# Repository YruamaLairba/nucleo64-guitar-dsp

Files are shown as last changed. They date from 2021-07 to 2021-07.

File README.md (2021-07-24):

# Nucleo guitar DSP

A STM32 Nucleo expansion board to transform your Nucleo board into guitar effect
processor.

## Description

This is a STM32 Nucleo expansion board to turn Nucleo Development board into
a guitar effect processor. It's designed targeting specifically the
nucleo-f441RE board while being usable with other boards, so it may be usable
with most nucleo64 and nucleo144 board.

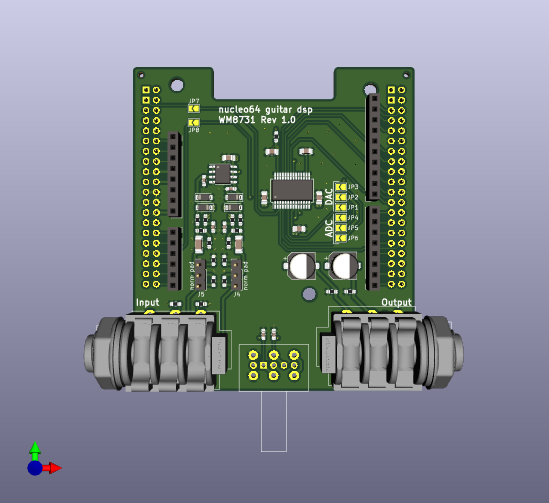
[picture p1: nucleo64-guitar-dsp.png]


## Some features:
 * can be used with passive or active guitar, thanks to j4 and j5 selectors
   (mini switches can be used instead of pin headers and jumpers).
   * "norm" is for passive guitar and voltage source below 1vrms. Input
     impedance is ~1 Megohm
   * "pad" is for active source with voltage higher than 1vrms, It apply ~18db
     attenuation. Input impedance is 37 ~ 38kohm.
   * J4 is for left channel and J5 for the right channel. 
 * Stereo input, so it can be used for stuff other than guitar.
 * Output usable with headphone.

## Setup solder bridge

I assume a Nucleo-f411re board. Depending the used Nucleo board, pinout can be
different and things can have different name or may even not exist. Check
various datasheet before doing anything.

JP1 - JP3, connect ADC output to a i2s serial data pin:
 * JP1 connects to PB15 (I2S2_SD)
 * JP2 connects to PB14 (I2S2ext_SD)
 * JP3 connects to PC12 (I2S3_SD)

JP4 - JP6, connect DAC input to a i2s serial data pin:
 * JP4 connects to PB15 (I2S2_SD)
 * JP5 connects to PB14 (I2S2ext_SD)
 * JP6 connects to PC12 (I2S3_SD)

JP7, connect PB13 (I2S2_CK) and PC10 (I2S3_CK), required when I2S3 is used

JP8, connect PB12 (I2S2_WS) and PA4 (I2S3_WS), required when I2S3 is used

Note: only I2S2 peripheral can be used as master.

## Missed consideration
In this first version, i missed or forgot some consideration:

 * **No output to output protection:** it mean boards can be damaged by a wrong
   setup. Putting resistor instead soldebridge on some solder jumper reduce the
risk

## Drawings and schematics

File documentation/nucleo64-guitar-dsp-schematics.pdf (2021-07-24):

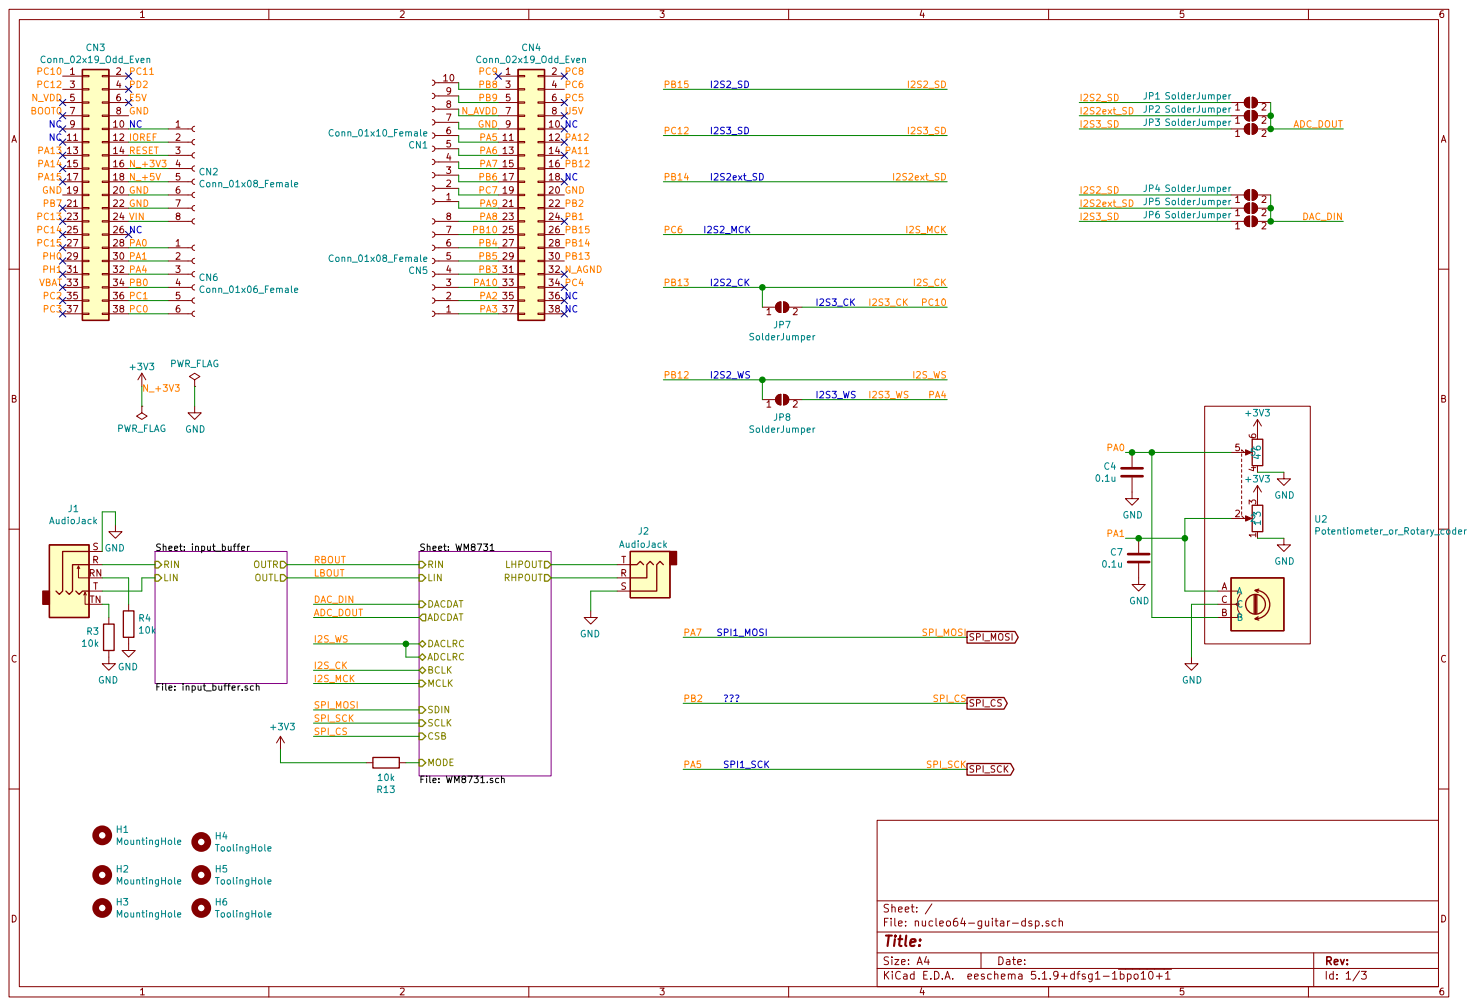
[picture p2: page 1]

File: nucleo64-guitar-dsp.sch Sheet: / Sheet: input_buffer
File: input_buffer.sch OUTR OUTL RIN
LIN

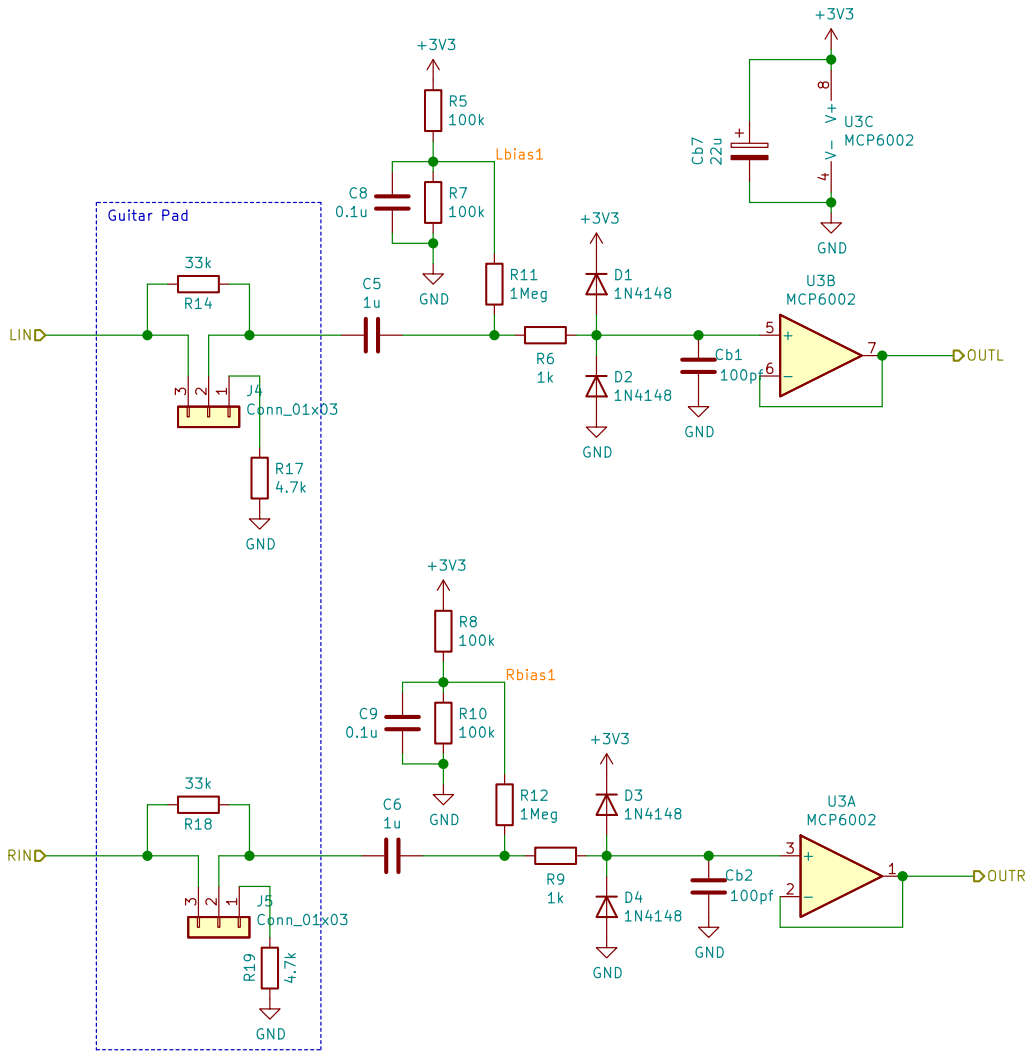
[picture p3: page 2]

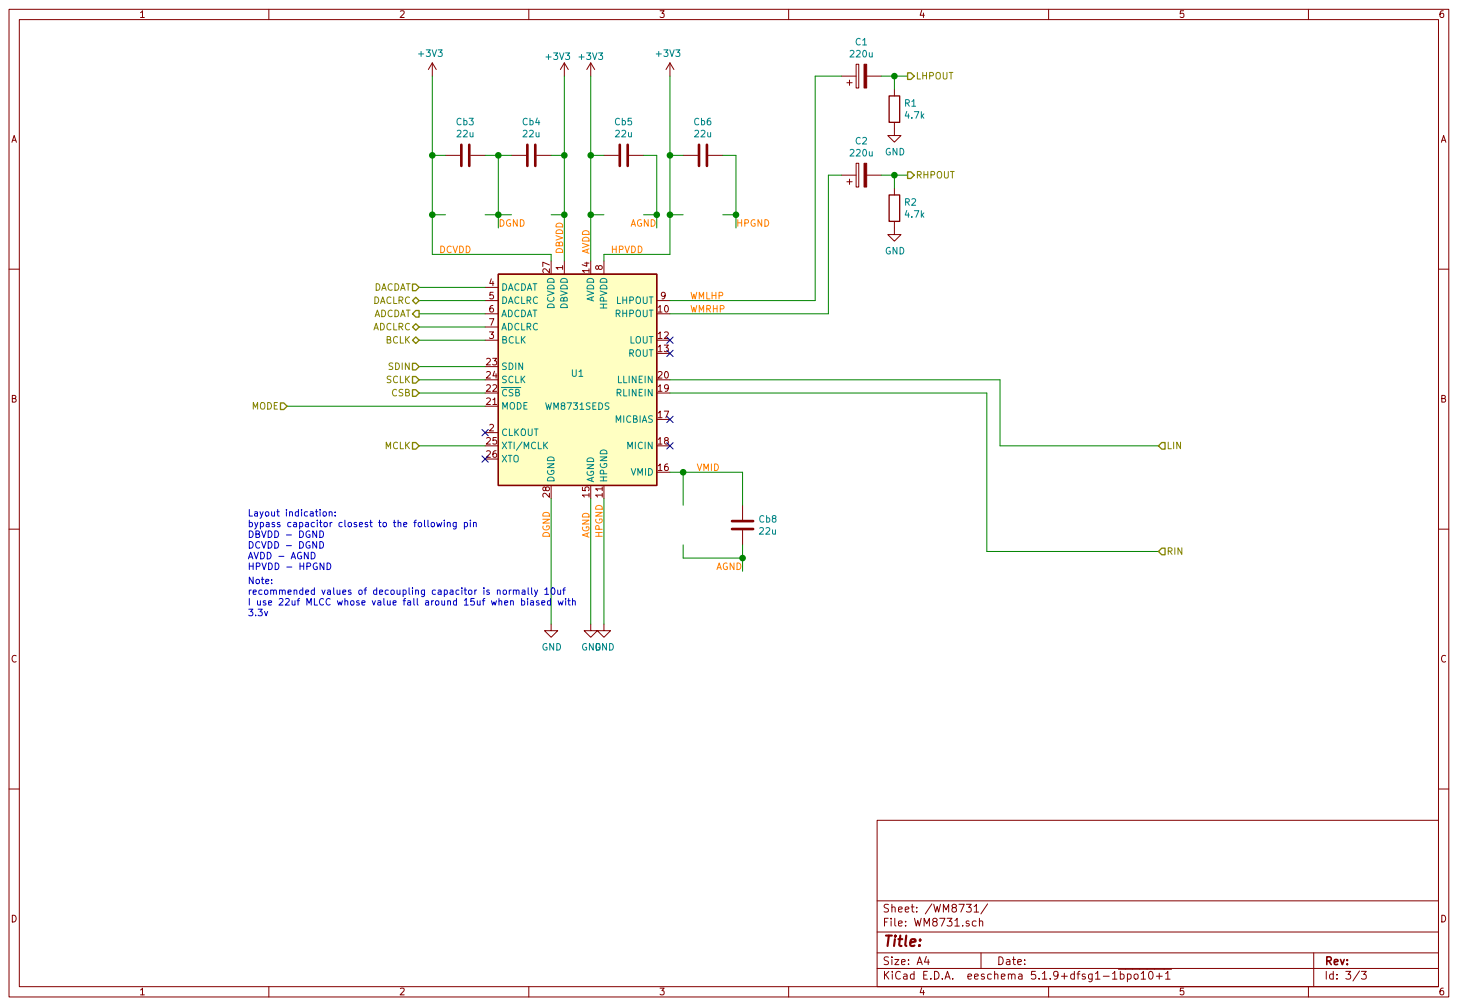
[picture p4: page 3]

3.3v Layout indication:
bypass capacitor closest to the following pin DBVDD - DGND

DCVDD - DGND
AVDD - AGND
HPVDD - HPGND
Note: recommended values of decoupling capacitor is normally 10uf

I use 22uf MLCC whose value fall around 15uf when biased with

Id: 3/3 Title: File: WM8731.sch Sheet: /WM8731/ GND

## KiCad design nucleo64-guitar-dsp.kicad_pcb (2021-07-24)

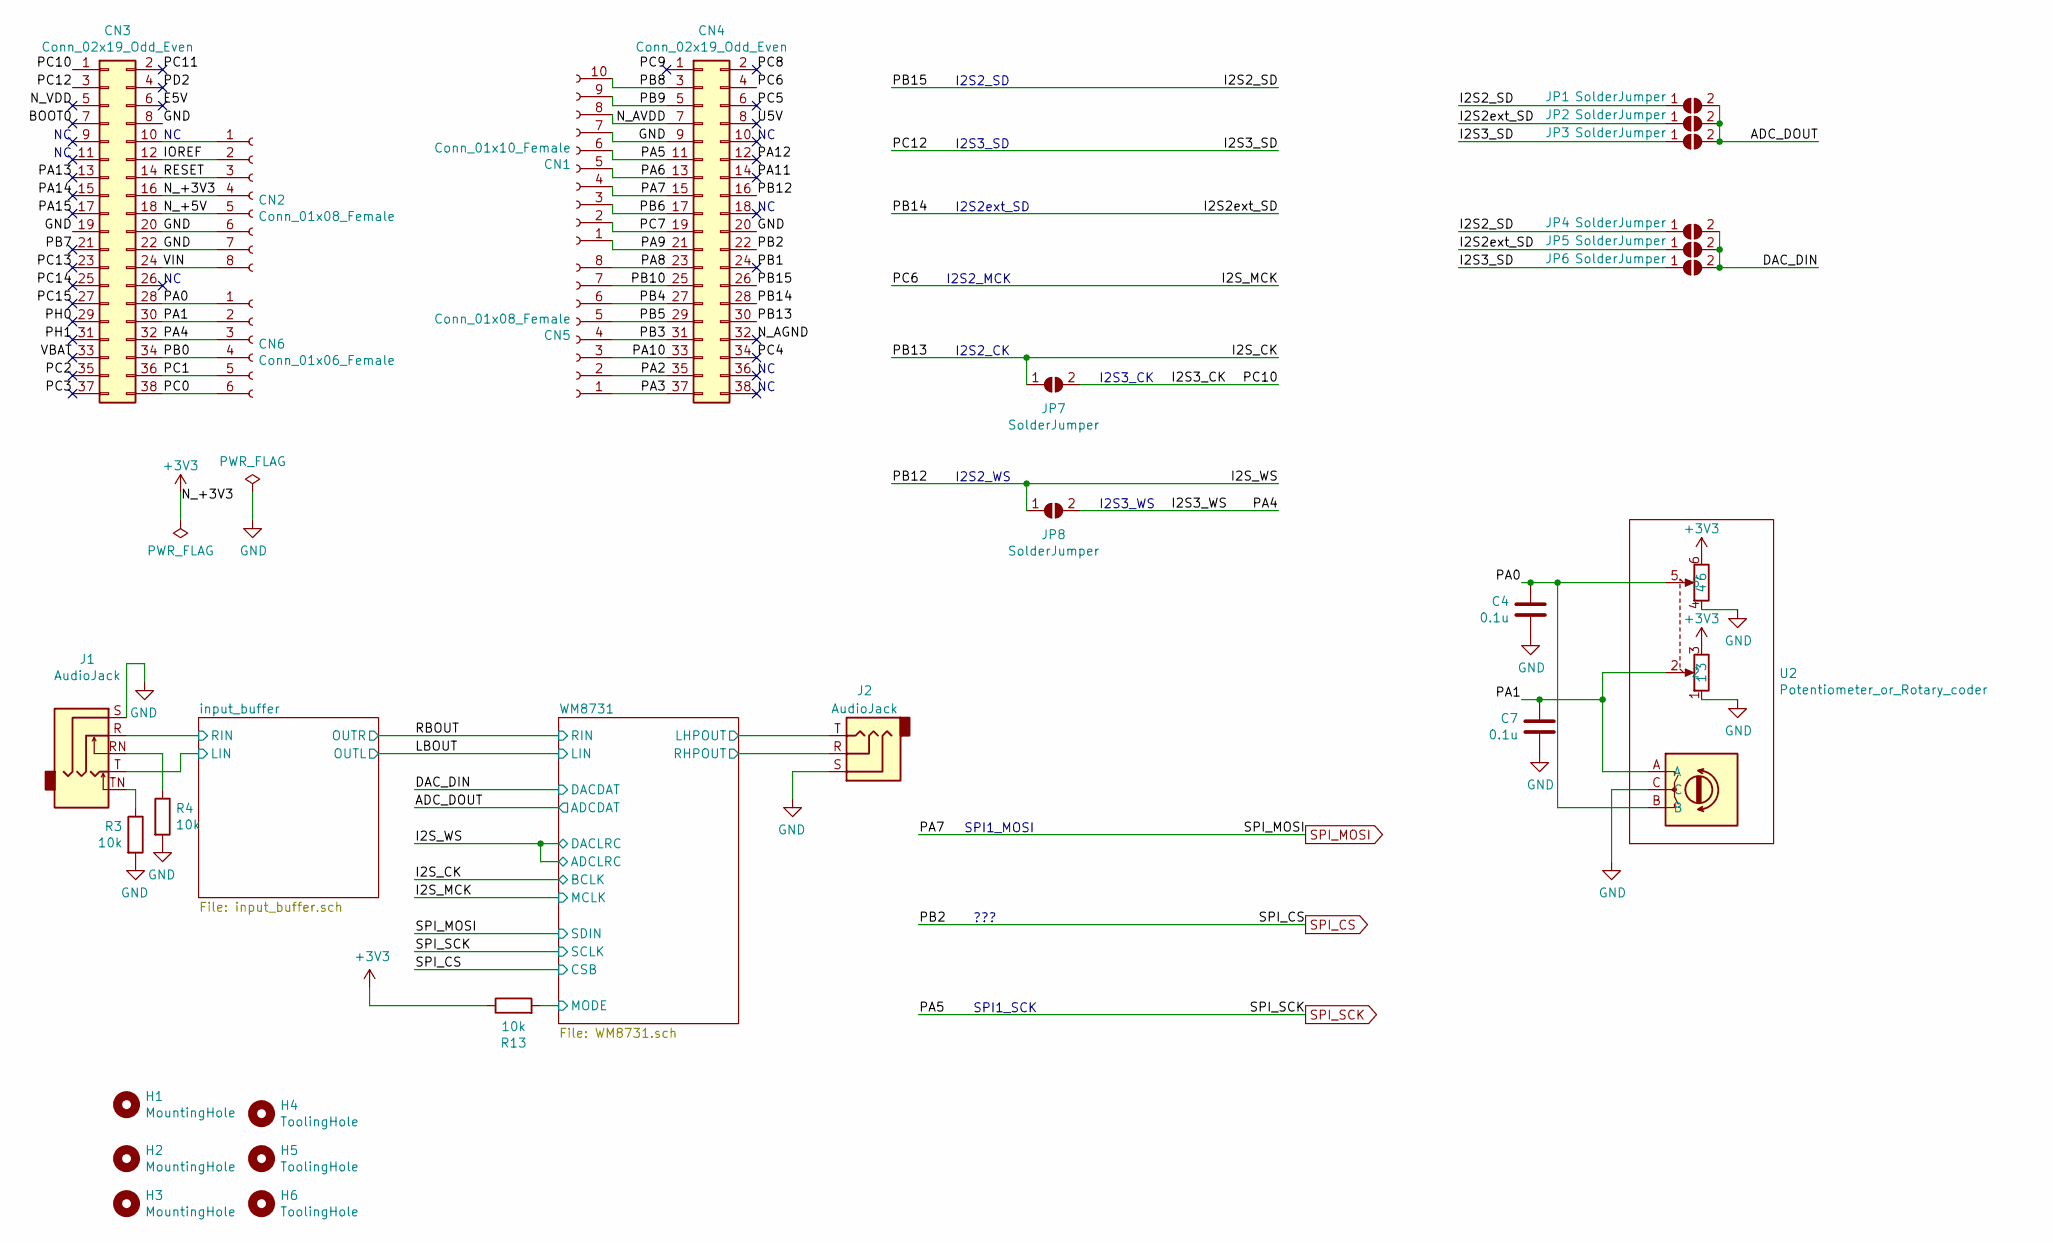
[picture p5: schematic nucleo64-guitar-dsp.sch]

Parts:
C4, C7: 0.1u; C_0603_1608Metric_Pad1.08x0.95mm_HandSolder; LCSC Part C14663
CN1: Conn_01x10_Female; PinSocket_1x10_P2.54mm_Vertical
CN2, CN5: Conn_01x08_Female; PinSocket_1x08_P2.54mm_Vertical
CN3, CN4: Conn_02x19_Odd_Even; PinSocket_2x19_P2.54mm_Vertical
CN6: Conn_01x06_Female; PinSocket_1x06_P2.54mm_Vertical
H1, H2, H3: MountingHole; MountingHole_3.2mm_M3_ISO14580
H4, H5, H6: ToolingHole; JLCPCB_2_layer
J1, J2: AudioJack; Jack_6.35mm_Neutrik_NM+NR
JP1, JP2, JP3, JP4, JP5, JP6, JP7, JP8: SolderJumper; SolderJumper-2_P1.3mm_Open_TrianglePad1.0x1.5mm
R3, R4, R13: 10k; R_0603_1608Metric_Pad0.98x0.95mm_HandSolder; LCSC Part C25804
U2: Potentiometer_or_Rotary_coder; Potentiometer_or_Rotary_Encoder

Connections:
+3V3: CN2.4, CN3.16, R13.1, U2.3, U2.6; also elsewhere on the board
/ADC_DOUT: JP1.2 (B), JP2.2 (B), JP3.2 (B); also elsewhere on the board
/BOOT0: CN3.7
/DAC_DIN: JP4.2 (B), JP5.2 (B), JP6.2 (B); also elsewhere on the board
/E5V: CN3.6
/I2S2_SD: CN4.26, JP1.1 (A), JP4.1 (A)
/I2S2ext_SD: CN4.28, JP2.1 (A), JP5.1 (A)
/I2S3_CK: CN3.1, JP7.2 (B)
/I2S3_SD: CN3.3, JP3.1 (A), JP6.1 (A)
/I2S3_WS: CN3.32, CN6.3, JP8.2 (B)
/I2S_CK: CN4.30, JP7.1 (A); also elsewhere on the board
/I2S_MCK: CN4.4; also elsewhere on the board
/I2S_WS: CN4.16, JP8.1 (A); also elsewhere on the board
/IOREF: CN2.2, CN3.12
/N_+5V: CN2.5, CN3.18
/N_AGND: CN4.32
/N_AVDD: CN1.8, CN4.7
/N_VDD: CN3.5
/PA0: C4.1, CN3.28, CN6.1, U2.5, U2.B
/PA1: C7.1, CN3.30, CN6.2, U2.2, U2.A
/PA2: CN4.35, CN5.2
/PA3: CN4.37, CN5.1
/PA6: CN1.5, CN4.13
/PA8: CN4.23, CN5.8
/PA9: CN1.1, CN4.21
/PA10: CN4.33, CN5.3
/PA11: CN4.14
/PA12: CN4.12
/PA13: CN3.13
/PA14: CN3.15
/PA15: CN3.17
/PB0: CN3.34, CN6.4
/PB1: CN4.24
/PB3: CN4.31, CN5.4
/PB4: CN4.27, CN5.6
/PB5: CN4.29, CN5.5
/PB6: CN1.3, CN4.17
/PB7: CN3.21
/PB8: CN1.10, CN4.3
/PB9: CN1.9, CN4.5
/PB10: CN4.25, CN5.7
/PC0: CN3.38, CN6.6
/PC1: CN3.36, CN6.5
/PC2: CN3.35
/PC3: CN3.37
/PC4: CN4.34
/PC5: CN4.6
/PC7: CN1.2, CN4.19
/PC8: CN4.2
/PC9: CN4.1
/PC11: CN3.2
/PC13: CN3.23
/PC14: CN3.25
/PC15: CN3.27
/PD2: CN3.4
/PH0: CN3.29
/PH1: CN3.31
/RESET: CN2.3, CN3.14
/U5V: CN4.8
/VBAT: CN3.33
/VIN: CN2.8, CN3.24
/WM8731/LHPOUT: J2.T; also elsewhere on the board
/WM8731/MODE: R13.2; also elsewhere on the board
/WM8731/RHPOUT: J2.R; also elsewhere on the board
/input_buffer/LIN: J1.T; also elsewhere on the board
/input_buffer/RIN: J1.R; also elsewhere on the board
GND: C4.2, C7.2, CN1.7, CN2.6, CN2.7, CN3.8, CN3.19, CN3.20, CN3.22, CN4.9, CN4.20, J1.S, J2.S, R3.2, R4.2, U2.1, U2.4, U2.C; also elsewhere on the board
unnamed: CN2.1, CN3.10
unnamed: J1.RN, R4.1
unnamed: J1.TN, R3.1
SPI_CS: CN4.22; also elsewhere on the board
SPI_MOSI: CN1.4, CN4.15; also elsewhere on the board
SPI_SCK: CN1.6, CN4.11; also elsewhere on the board

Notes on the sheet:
I2S2_WS
I2S2_CK
I2S2ext_SD
I2S2_SD
I2S2_MCK
I2S3_WS
I2S3_CK
I2S3_SD
SPI1_SCK
???
SPI1_MOSI

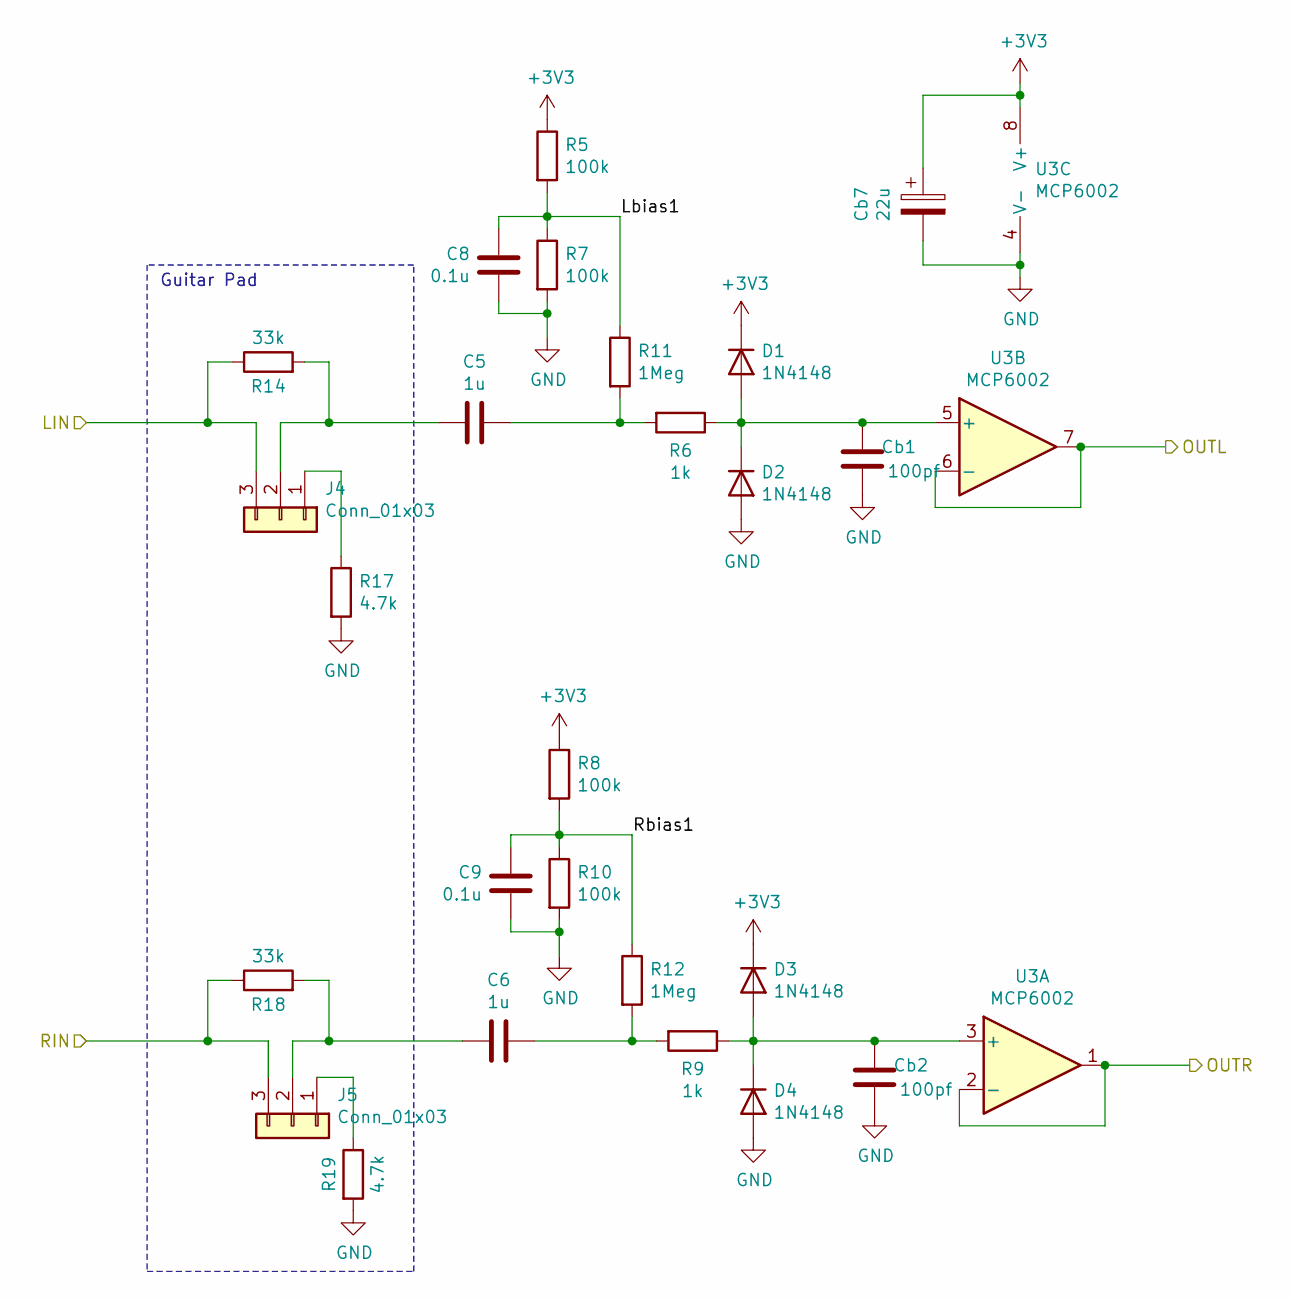
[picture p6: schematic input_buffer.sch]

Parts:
C5, C6: 1u; C_1206_3216Metric_Pad1.33x1.80mm_HandSolder; LCSC Part C1848
C8, C9: 0.1u; C_0603_1608Metric_Pad1.08x0.95mm_HandSolder; LCSC Part C14663
Cb1, Cb2: 100pf; C_0603_1608Metric_Pad1.08x0.95mm_HandSolder; LCSC Part C14858
Cb7: 22u; C_0805_2012Metric_Pad1.18x1.45mm_HandSolder; LCSC Part C45783
D1, D2, D3, D4: 1N4148; D_SOD-123; LCSC Part C81598
J4, J5: Conn_01x03; PinHeader_1x03_P2.54mm_Vertical
R5, R7, R8, R10: 100k; R_0603_1608Metric_Pad0.98x0.95mm_HandSolder; LCSC Part C22938
R6, R9: 1k; R_0603_1608Metric_Pad0.98x0.95mm_HandSolder; LCSC Part C21190
R11, R12: 1Meg; R_0603_1608Metric_Pad0.98x0.95mm_HandSolder; LCSC Part C22935
R14, R18: 33k; R_0603_1608Metric_Pad0.98x0.95mm_HandSolder; LCSC Part C4216
R17, R19: 4.7k; R_0603_1608Metric_Pad0.98x0.95mm_HandSolder; LCSC Part C23162
U3: MCP6002; SOIC-8_3.9x4.9mm_P1.27mm; LCSC Part C7377

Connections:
+3V3: Cb7.1, D1.1 (K), D3.1 (K), R5.1, R8.1, U3.8 (V+); also elsewhere on the board
/LBOUT: U3.6 (-), U3.7; also elsewhere on the board
/RBOUT: U3.1, U3.2 (-); also elsewhere on the board
/input_buffer/LIN: J4.3, R14.1; also elsewhere on the board
/input_buffer/Lbias1: C8.1, R5.2, R7.1, R11.1
/input_buffer/RIN: J5.3, R18.1; also elsewhere on the board
/input_buffer/Rbias1: C9.1, R8.2, R10.1, R12.1
GND: C8.2, C9.2, Cb1.1, Cb2.1, Cb7.2, D2.2 (A), D4.2 (A), R7.2, R10.2, R17.2, R19.2, U3.4 (V-); also elsewhere on the board
unnamed: C5.1, R6.2, R11.2
unnamed: C5.2, J4.2, R14.2
unnamed: C6.1, R9.2, R12.2
unnamed: C6.2, J5.2, R18.2
unnamed: Cb1.2, D1.2 (A), D2.1 (K), R6.1, U3.5 (+)
unnamed: Cb2.2, D3.2 (A), D4.1 (K), R9.1, U3.3 (+)
unnamed: J4.1, R17.1
unnamed: J5.1, R19.1

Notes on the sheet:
Guitar Pad

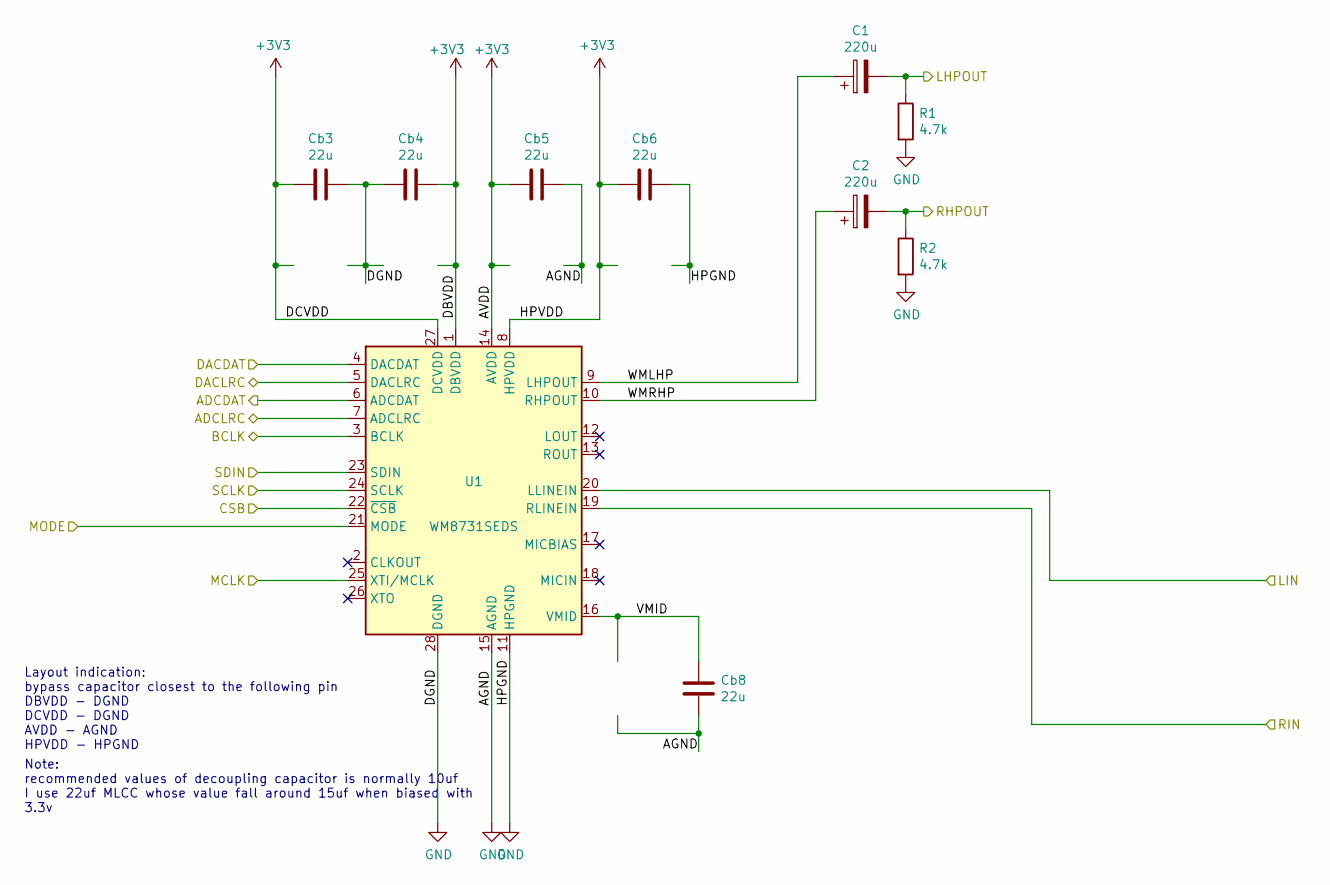
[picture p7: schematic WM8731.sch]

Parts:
C1, C2: 220u; CP_Elec_6.3x7.7; LCSC Part C127968
Cb3, Cb4, Cb5, Cb6, Cb8: 22u; C_0805_2012Metric_Pad1.18x1.45mm_HandSolder; LCSC Part C45783
R1, R2: 4.7k; R_0603_1608Metric_Pad0.98x0.95mm_HandSolder; LCSC Part C23162
U1: WM8731SEDS; SSOP-28_5.3x10.2mm_P0.65mm; LCSC Part C323837

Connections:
+3V3: Cb3.1, Cb4.1, Cb5.1, Cb6.1, U1.1 (DBVDD), U1.8 (HPVDD), U1.14 (AVDD), U1.27 (DCVDD); also elsewhere on the board
/ADC_DOUT: U1.6 (ADCDAT); also elsewhere on the board
/DAC_DIN: U1.4 (DACDAT); also elsewhere on the board
/I2S_CK: U1.3 (BCLK); also elsewhere on the board
/I2S_MCK: U1.25 (XTI/MCLK); also elsewhere on the board
/I2S_WS: U1.5 (DACLRC), U1.7 (ADCLRC); also elsewhere on the board
/LBOUT: U1.20 (LLINEIN); also elsewhere on the board
/RBOUT: U1.19 (RLINEIN); also elsewhere on the board
/WM8731/LHPOUT: C1.2, R1.1; also elsewhere on the board
/WM8731/MODE: U1.21 (MODE); also elsewhere on the board
/WM8731/RHPOUT: C2.2, R2.1; also elsewhere on the board
/WM8731/VMID: Cb8.1, U1.16 (VMID)
/WM8731/WMLHP: C1.1, U1.9 (LHPOUT)
/WM8731/WMRHP: C2.1, U1.10 (RHPOUT)
GND: Cb3.2, Cb4.2, Cb5.2, Cb6.2, Cb8.2, R1.2, R2.2, U1.11 (HPGND), U1.15 (AGND), U1.28 (DGND); also elsewhere on the board
SPI_CS: U1.22 (~CSB); also elsewhere on the board
SPI_MOSI: U1.23 (SDIN); also elsewhere on the board
SPI_SCK: U1.24 (SCLK); also elsewhere on the board

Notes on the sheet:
Layout indication: bypass capacitor closest to the following pin DBVDD - DGND DCVDD - DGND AVDD - AGND HPVDD - HPGND
Note: recommended values of decoupling capacitor is normally 10uf I use 22uf MLCC whose value fall around 15uf when biased with 3.3v

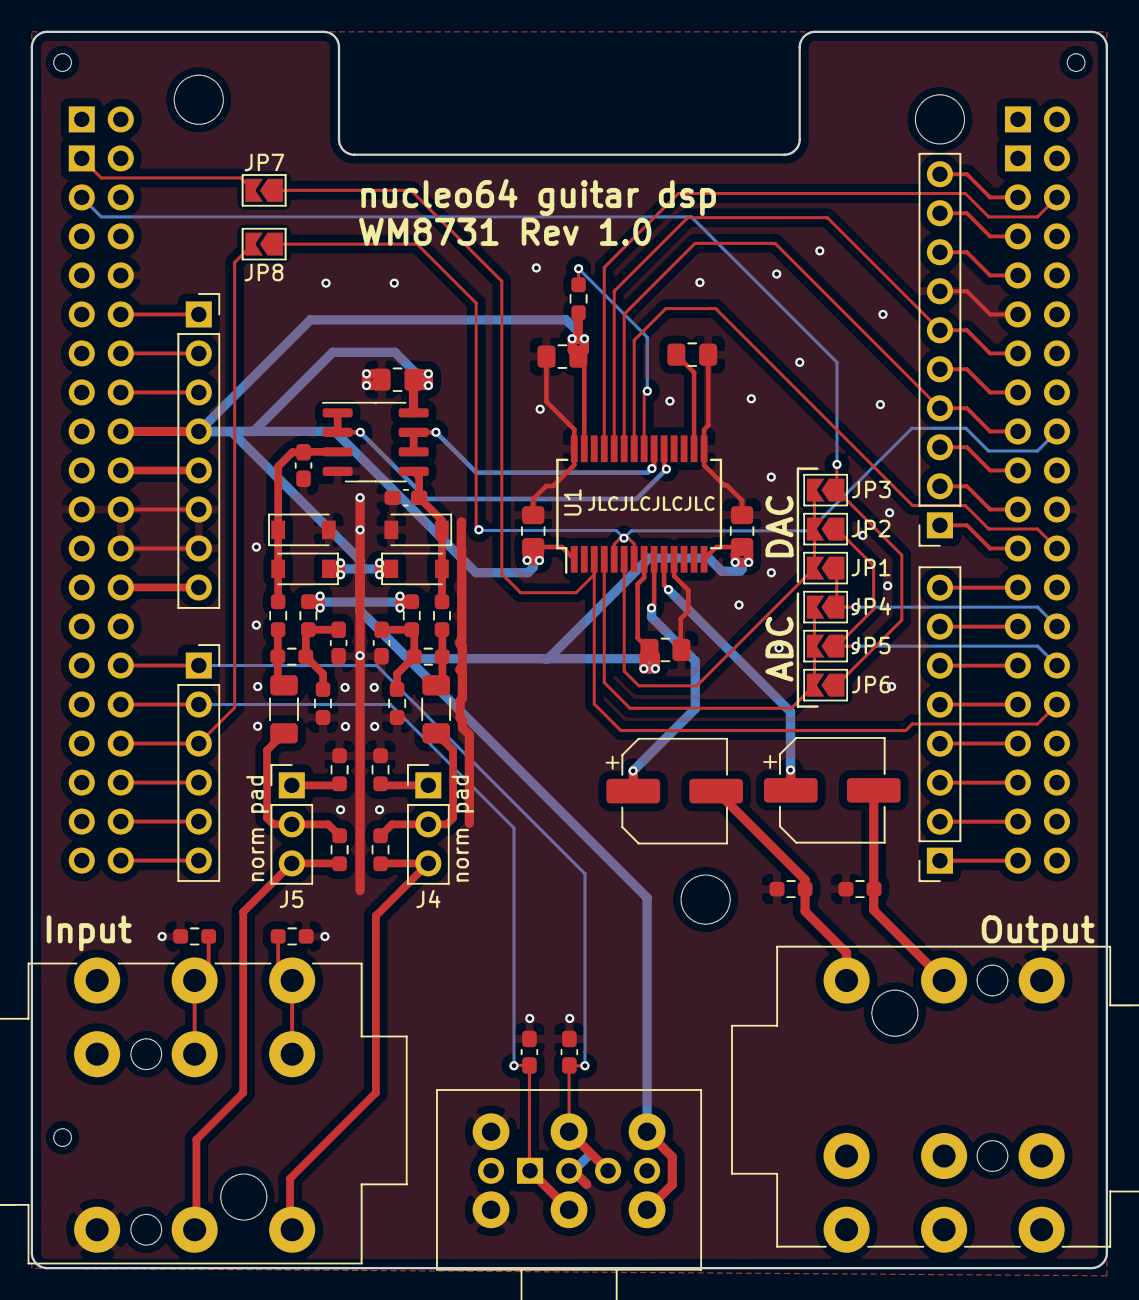
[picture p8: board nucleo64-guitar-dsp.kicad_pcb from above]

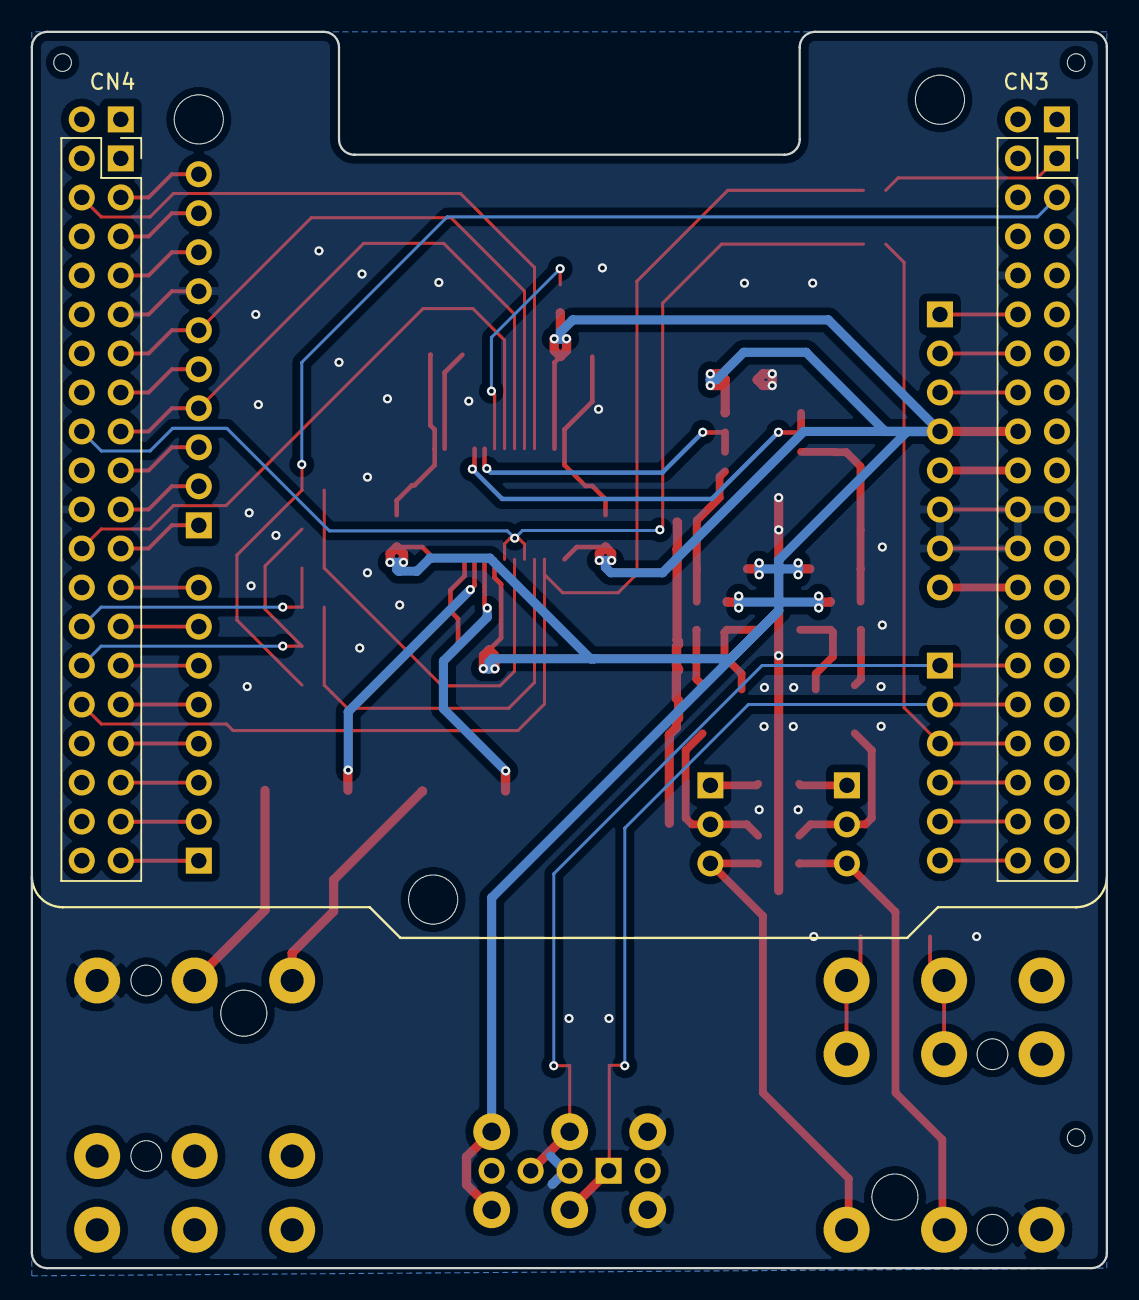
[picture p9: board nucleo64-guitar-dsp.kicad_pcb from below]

Board: 4 copper layers, 70.0 x 80.5 mm, 64 parts (6 on the bottom side), 62 nets.
